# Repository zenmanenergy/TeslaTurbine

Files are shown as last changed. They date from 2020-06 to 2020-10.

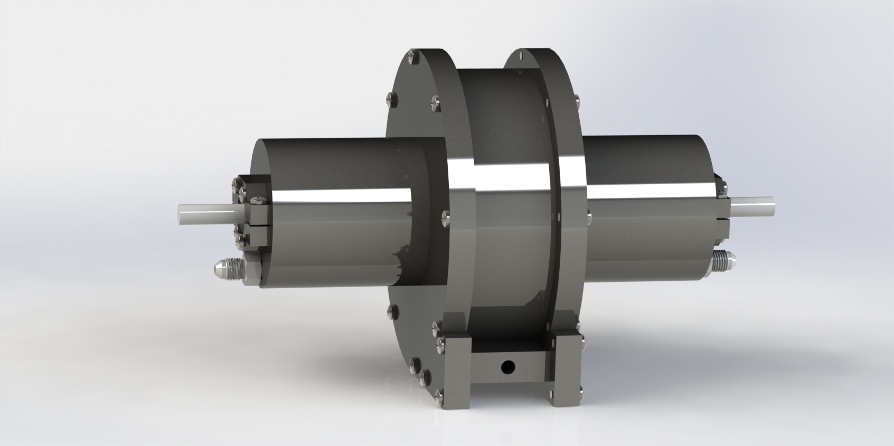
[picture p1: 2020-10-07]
Pump/138mm/Solidworks 2015/renderings/Tesla Pump2.JPG

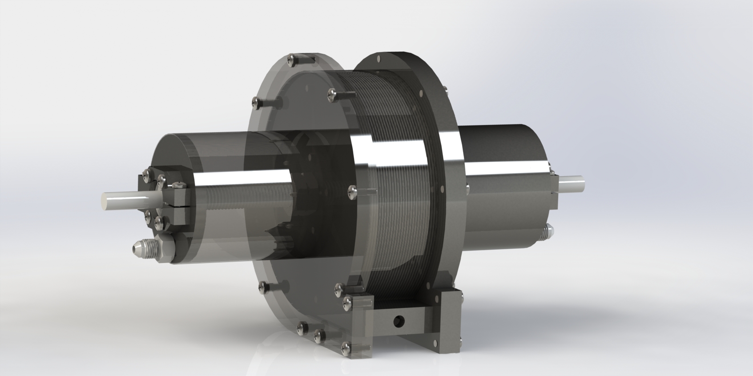
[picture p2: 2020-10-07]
Pump/138mm/Solidworks 2015/renderings/Tesla Pump transparent.JPG

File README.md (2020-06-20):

# Tesla Turbine and Pump

*this is a work in progress, please fork this repository and help edit the README files!*

Nikola Tesla's turbine is a unique turbine in that it does not contain any buckets or blades. This turbine consists of a 'runner' of very thin, flat disks that are keyed to an axle. Each of the disks on the runner is seperated from the other disks with a thin star shaped spacer. Near the axle, each disks contains 8 holes in them. Unlike bucket and blade style turbines, the Tesla turbine works based on a fluid's properties of viscosity and adhesion. 

The turbine operates in two modes. If the axle is spun using another mechanical device, such as a motor, it becomes a pump. In this mode it sucks water into the holes near the center of the disk and ejects the fluid from the tangent of the disks. If a high velocity fluid is injected at the tangent of the disks it becomes a turbine. In this mode the fluid causes the axle to spin at a high velocity.

## What is this repository?

This repository is made up of CAD drawings based on Tesla's patents. These drawings can be used to machine full scale turbines and pumps. Some very minor liberties have been taken in his patents primarily for ease of machinability. The current design is based on a layered approach, cutting parts with a laser cutter instead of a CNC mill. This method should dramatically reduce the time needed to machine parts. 

> `All drawings are done in metric!`

## File format

Originally these drawings were made using Solidworks 2015. Since Solidworks is not a free CAD tool, additional file formats are included in the repository including STL and DXF. As this repository grows additional formats will be included.

# More about Tesla Turbine

## Patents

> 1913 Patents

> 1921 Patent

## Turbine Mode

## Pump Mode

## History of the Tesla Turbine

## Quotes
*The idea on which all steam engines - gas engines, too - have been built in the past was that there must be something solid and substantial for the steam to push against. The piston of a reciprocating engine and the blades and buckets of modern turbine engines are examples. That idea has made them rather complicated devices, requiring careful fitting for efficient operation, great expense for repairs and especially in the case of turbines, great liability to damage. It has also made them bulky and heavy.*

*What I have done is to discard entirely the idea that there must be a solid wall in front of the steam and to apply in a practical way, for the first time, two properties which every physicist knows to be common to all fluids (including steam and gas) but which have not been utilized. These are adhesion and viscosity.*

*You know that water has a tendence to stick to a solid surface. That is the property of adhesion which every fluid - gas, steam, water or whatever it be- possesses. You also know that a drop of water tends to retain its form, even against a considerable force, such as gravity. That is viscosity, the tendency to resist molecular separation, and all the fluids have this property too.*

*It occured to me that if I should take circular disks, mount them on a shaft through their centers, space them a little distance apart and let some fluid under pressure, such as steam or gas, enter the interstices between the disks in a tangential direction, the fluid, as it moved, owing to these property of adhesion and viscosity, would tend to drag the disks along and transmit its energy to them. It happened just as I had thought it would, and that is the principle of this turbine. It utilitizes the very properties which cause all the loss of power in other turbines.*

-Nikola Tesla, March 1920 

## Traditional Turbines
Most turbines work using a principle known as impulse or reaction. An impulse turbine such as a Pelton wheel or a Crossflow turbine work when a high velocity fluid strikes a bucket (Pelton wheel) or a twist blade (Crossflow turbine). A reaction turbine such as a Francic wheel or a Curtis turbine work using a curved blade that produces a lift force creating a higher speed than an impulse turbine.

## Advantages of Tesla Turbine over Traditional Turbines

5/16" shaft:
abec-5 Bearings:
rated for 48,000 RPM
https://www.mcmaster.com/57155K338

5/16" washers:
316 stainless steel
https://www.mcmaster.com/90107A030

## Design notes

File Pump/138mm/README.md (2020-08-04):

## 138mm Pump

> As of 6/23/2020

These are drawings for a Tesla Pump that have 138mm diameter disks. They are based on a mixture of the patents from the 1921 runner. This is a modification from the 100mm disk. It does not contain a volute casing. I learned that the volute casing is the most expensive part to machine. So I have opted to use tubing instead allowing for a larger number of disks. All parts except for the axle and the tube section of the stator are designed to be laser cut out of flat stock and should not require any CNC machining. Once the parts are laser cut, many of them need to be welded together to seal the joints. 

I plan to use a mixture of metals on this pump. I will use Stainless steel 304 for the disks, spacers and axle. For the stator I will use aluminum. Aluminum is a tricky to weld. I will use a MIG spool gun to weld the joints.

The bearing mount is designed to all the runner AND bearings to be easily removed from the stator while still press fitting the axle onto the bearings. There is no threaded nut necessary for the axle, when the bearing mounts are bolted to the stator it will (should) squeeze the disks together. The 4 holes in the bearing mount need to be tapped for an M5 bolt.

Because the diameter of this turbine is small, to get the edge up to a high enough velocity means it requires high speed bearings. The bearings in these drawings can be purchased from mcmastercarr.com They are part number: 57155K338 rated for 48,000 rpm.

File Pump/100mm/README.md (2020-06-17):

## 100mm Pump

> As of 6/16/2020

These are drawings for a Tesla Pump that have 100mm diameter disks. They are based on a mixture of the patents from the 1913 stator and 1921 runner. I made some very minor design changes in the stator for ease of machining. All parts except for the axle are designed to be laser cut out of flat stock and should not require any CNC machining. Once the parts are laser cut, many of them need to be welded together to seal the joints. 

The bearing mount is designed to all the runner AND bearings to be easily removed from the stator while still press fitting the axle onto the bearings. There is no threaded nut necessary for the axle, when the bearing mounts are bolted to the stator it will (should) squeeze the disks together. The 4 holes in the bearing mount need to be tapped for an M5 bolt.

Because the diameter of this turbine is small, to get the edge up to a high enough velocity means it requires high speed bearings. The bearings in these drawings can be purchased from mcmastercarr.com They are part number: 57155K338 rated for 48,000 rpm.

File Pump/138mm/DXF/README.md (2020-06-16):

## Solidworks 2015 drawings

The assembly for the Tesla Pump is in the /Tesla Pump folder. Some of the files are shared across the Turbine and pump. This folder structure helps to reduce duplicated work.

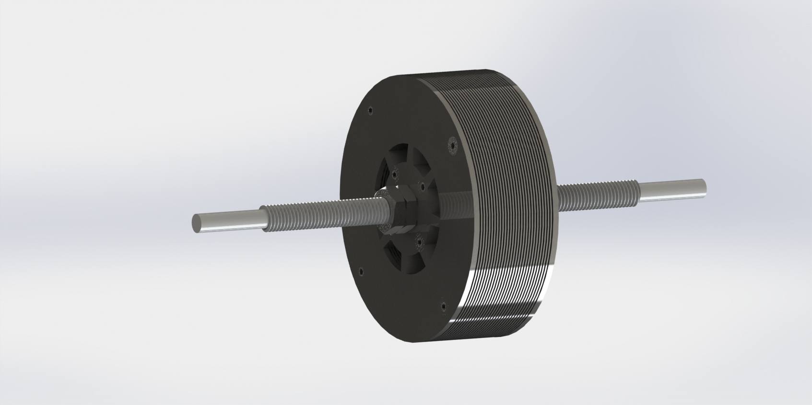
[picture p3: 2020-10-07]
Pump/138mm/Solidworks 2015/renderings/rotor.JPG

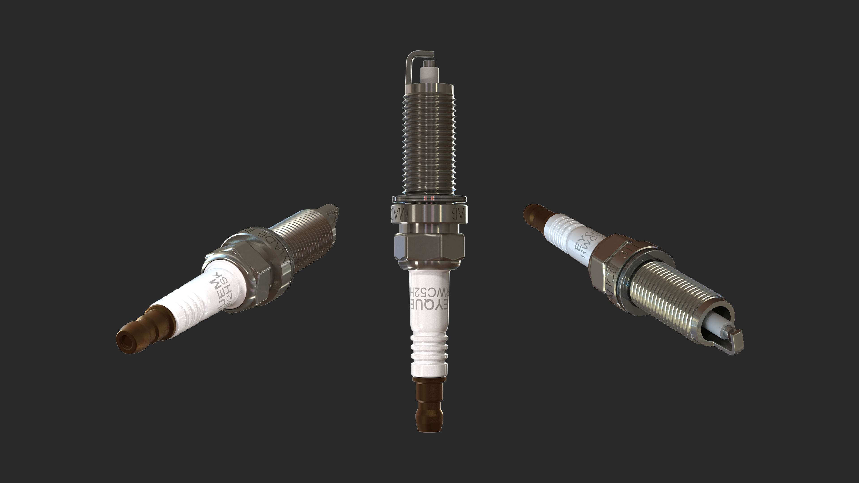
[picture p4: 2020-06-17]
Pulsejet/200mm/DXF/detonation chamber/spark-plug-61.snapshot.13/Renderings/Spark Plug - 3 view.png

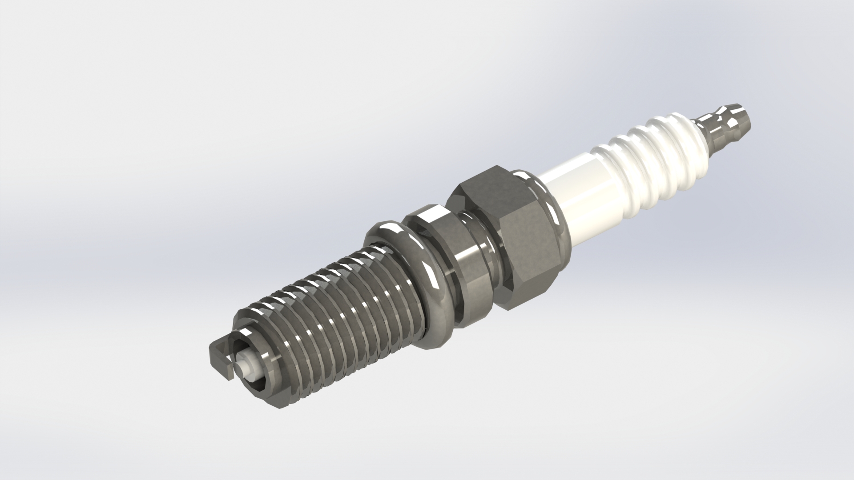
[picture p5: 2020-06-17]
Pulsejet/200mm/DXF/detonation chamber/Spark Plugs/preview 1.JPG

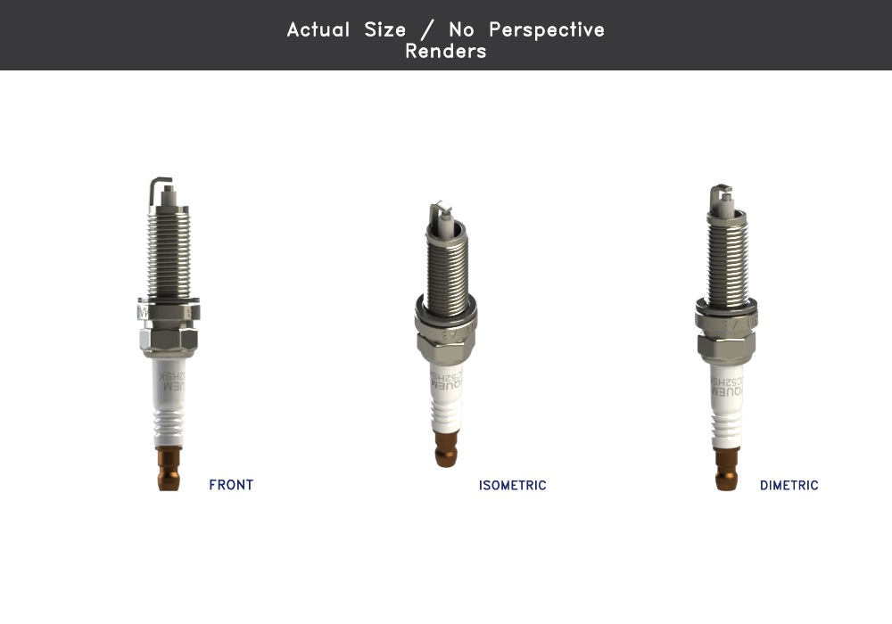
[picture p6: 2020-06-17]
Pulsejet/200mm/DXF/detonation chamber/spark-plug-61.snapshot.13/Renderings/Spark actual copy.png

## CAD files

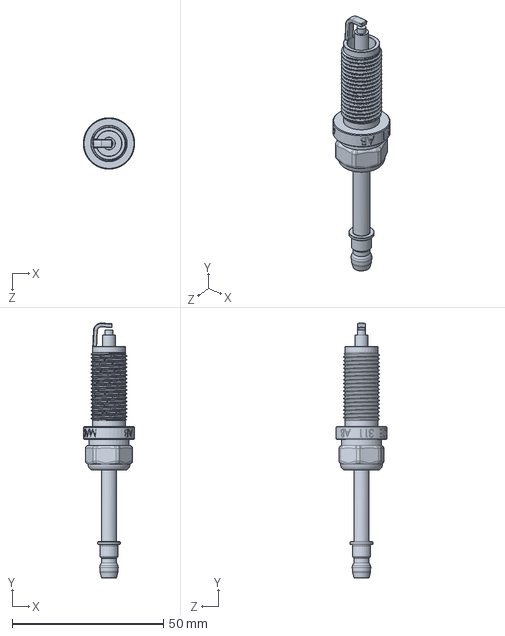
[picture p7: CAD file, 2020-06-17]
Pulsejet/200mm/DXF/detonation chamber/Spark Plugs/spark plug 1/Spark Plug - Main Body.SLDPRT
17.0 x 84.3 x 17.0 mm

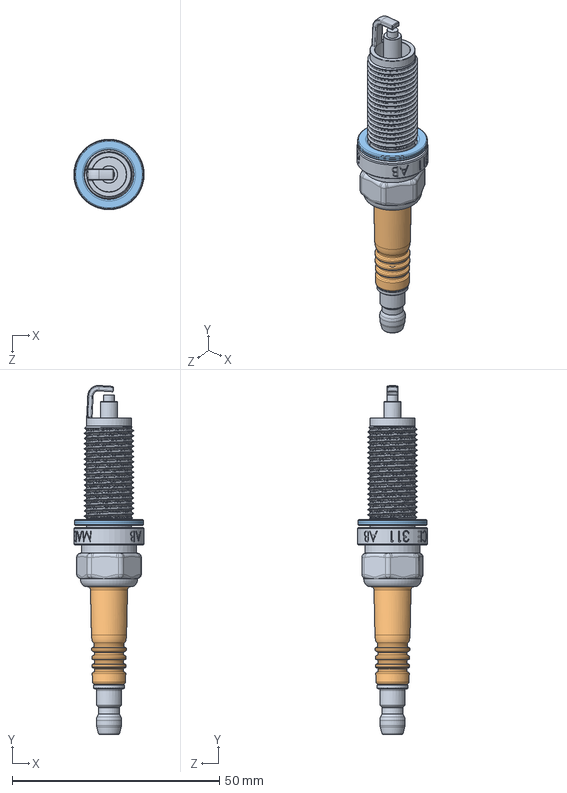
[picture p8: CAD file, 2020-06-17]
Pulsejet/200mm/DXF/detonation chamber/spark-plug-61.snapshot.13/Assembly/Spark Plug - assembly.SLDASM
17.0 x 84.3 x 17.0 mm
Spark Plug - Main Body
Insulator
Washer

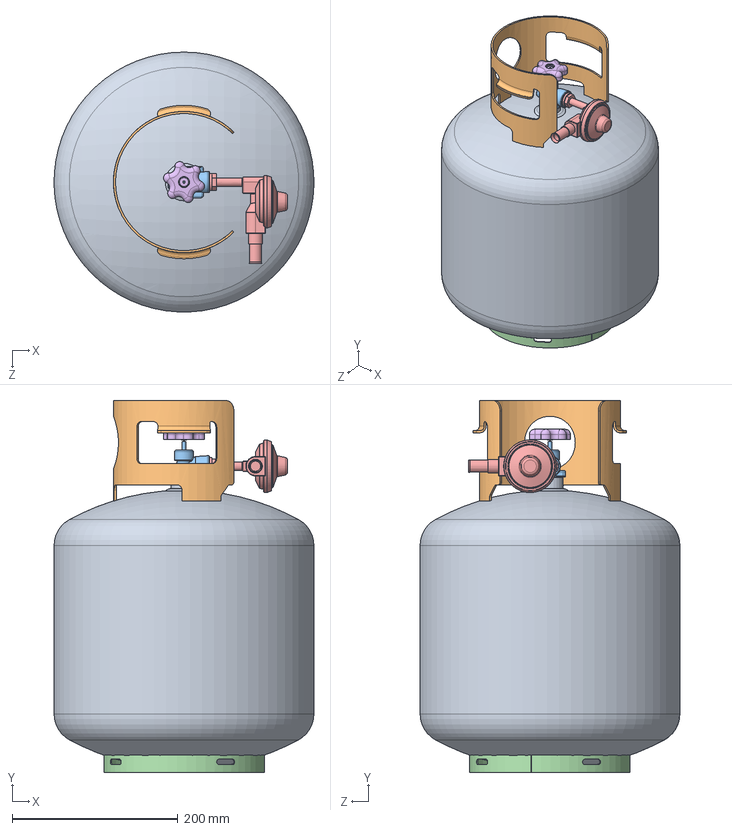
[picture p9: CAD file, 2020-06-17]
Pulsejet/200mm/Solidworks 2015/pipe fittings/Propane Tank/User Library-BBQ Liquid Propane Tank Assembly.SLDASM
313.2 x 448.3 x 313.1 mm
tank body2
tank_lifting_ring2
tank_valve_body2
tank_support_ring2
regulator2
gas_valve_knob2

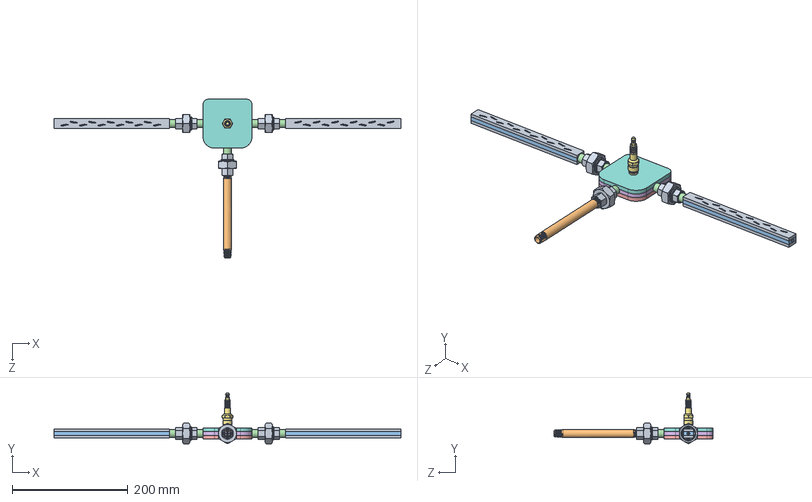
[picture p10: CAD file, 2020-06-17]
Pulsejet/200mm/Solidworks 2015/pulsejet/pulsejet.SLDASM
600.0 x 87.6 x 274.7 mm
bottom x 4
diverter x 22
channel x 2
9157K110_STD-WALL 304-304L SS THRD ONE END PIPE NIPPLE x 5
detonation bottom
detonation middle
SW3dPS
detonation top
4464K484_TYPE 304 STAINLESS STL THREADED PIPE FITTING x 3
4830K138_STANDARD-WALL 304 304L SS PIPE NIPPLE

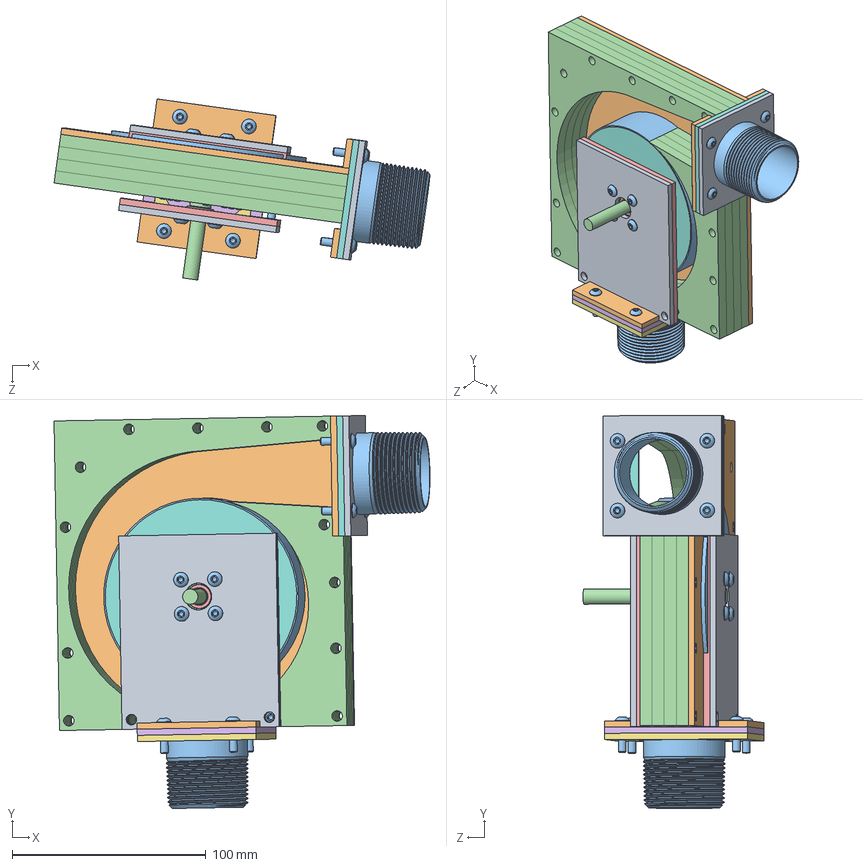
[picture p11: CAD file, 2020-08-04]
Pump/100mm/Solidworks 2015/Tesla Pump/Tesla Pump.SLDASM
194.3 x 203.1 x 93.6 mm
housing exhaust 1
housing1
socket button head cap screw_am x 17
housing 5 x 4
housing exhaust 2 x 2
input mount 1
input mount 2
exhaust mount 1
exhaust mount 2
exhaust bolt plate x 4
9157K260_STD-WALL 304-304L SS THRD ONE END PIPE NIPPLE x 2
axle
disk 1 x 13
spacer 1 x 14
keyway x 2
disk 0 x 2
92000A054_18-8 SS METRIC PAN HEAD PHIL MACHINE SCREW x 8
94150A305_TYPE 316 STAINLESS STEEL HEX NUT x 8
bearing mount 1 x 2
57155K338_STAINLESS STEEL BALL BEARING x 2

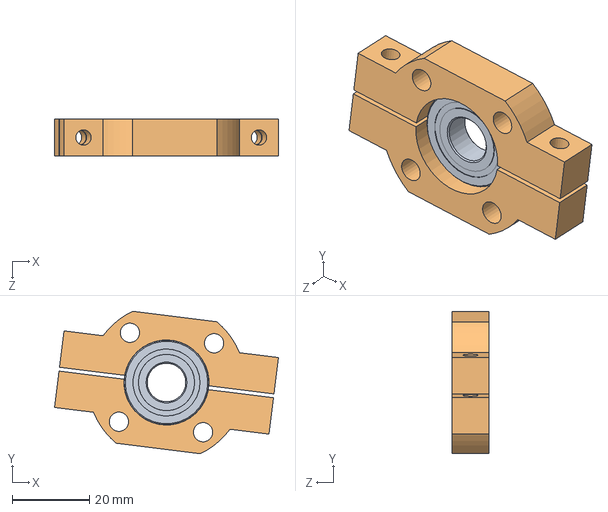
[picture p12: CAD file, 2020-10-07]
Pump/138mm/Solidworks 2015/bearing mount/bearing mount.SLDASM
58.1 x 36.9 x 9.50 mm
5972K164_BALL BEARING
bearing compression mount x 2

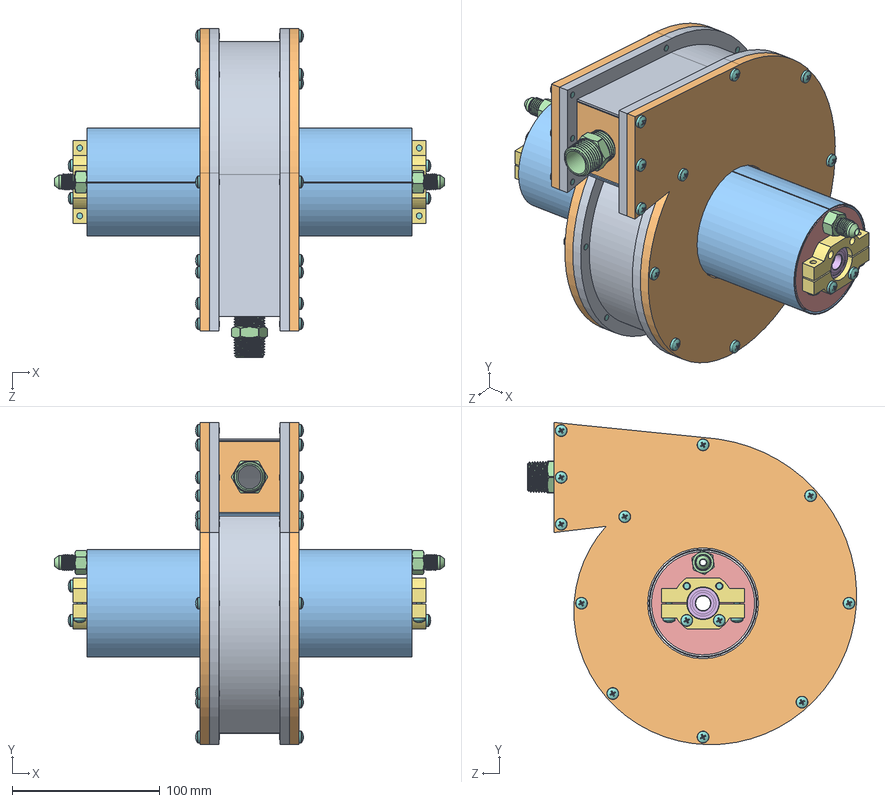
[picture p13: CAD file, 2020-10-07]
Pump/138mm/Solidworks 2015/pump stator/pump stator.SLDASM
263.7 x 217.9 x 222.6 mm
mounting ring x 2
end plate x 2
bearing pipe x 2
50695K162_STEEL 37 DEGREE FLARED TUBE FITTING x 2
tube end plate x 2
5972K164_BALL BEARING x 2
bearing compression mount x 4
pan cross head_am x 32
rolled housing
exhaust plate
exhaust plate top
4464K741_304 STAINLESS STEEL THREADED PIPE FITTING

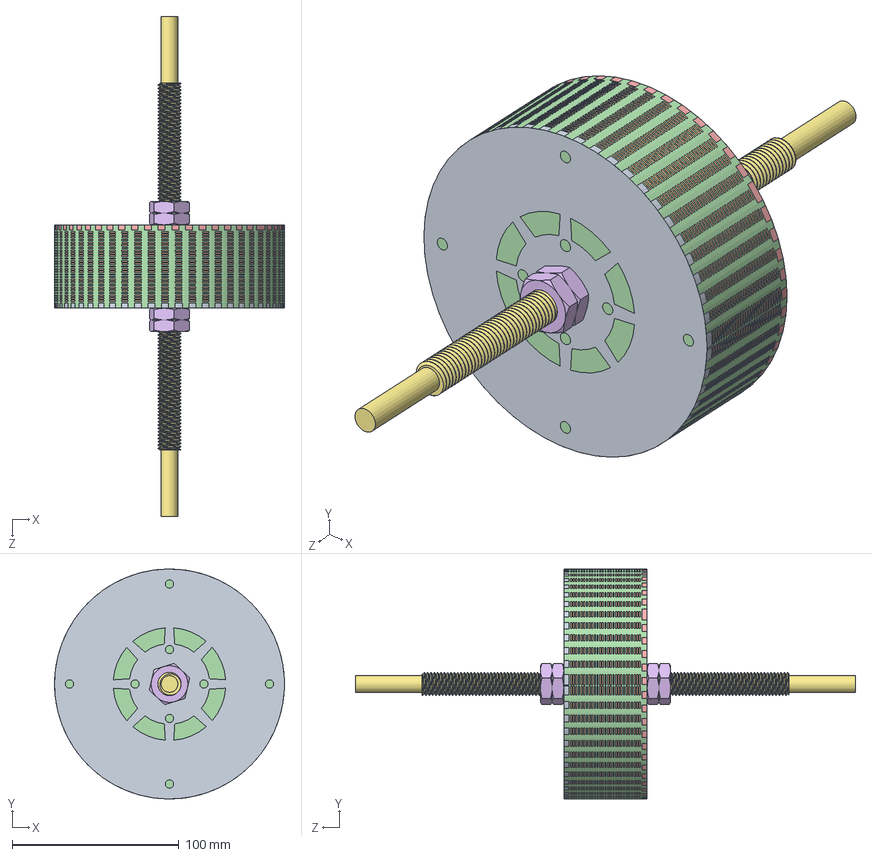
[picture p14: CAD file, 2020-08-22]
Pump/138mm/Solidworks 2015/rotor/rotor.SLDASM
138.0 x 138.0 x 300.0 mm
spacer 1 x 28
disk 1 x 27
keyway x 2
rotating part for simulation^rotor
disk x
90710A135_TYPE 18-8 SS THIN HEX NUT - DIN 439B x 4
axle
item_0060029_countersunk_screw_din_7991_m5x50_details_3 x 8
disk 0

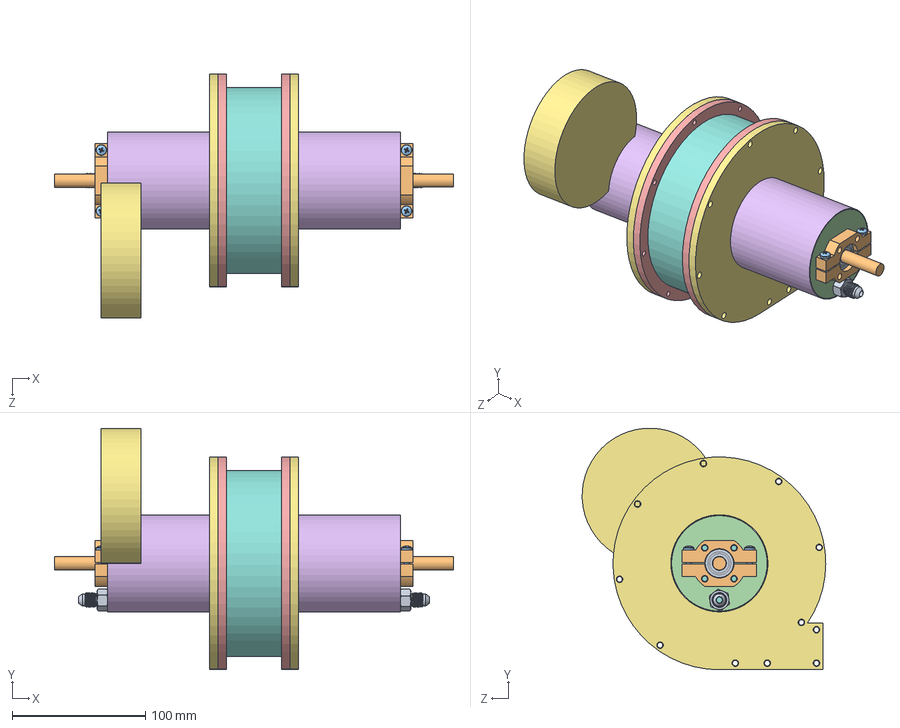
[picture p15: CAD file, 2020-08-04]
Pump/138mm/Solidworks 2015/Tesla Pump/Tesla Pump.SLDASM
300.0 x 181.6 x 183.1 mm
50695K162_STEEL 37 DEGREE FLARED TUBE FITTING x 2
exhaust plate top
exhaust plate
tube end plate x 2
mounting ring x 2
bearing pipe x 2
end plate 1 x 2
rolled housing
5972K164_BALL BEARING x 2
bearing compression mount x 4
pan cross head_am x 4
spacer 1 x 28
disk 1 x 27
keyway x 2
disk x
90710A135_TYPE 18-8 SS THIN HEX NUT - DIN 439B x 4
axle
item_0060029_countersunk_screw_din_7991_m5x50_details_3 x 8
disk 0

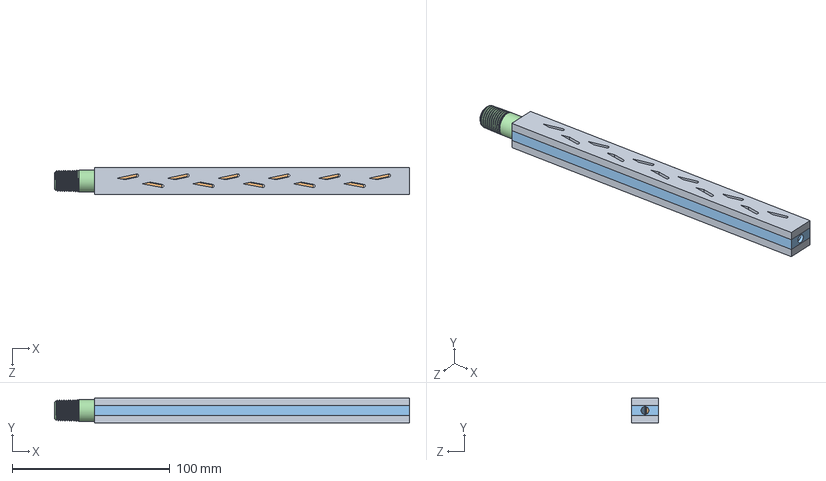
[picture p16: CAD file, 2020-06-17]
Pulsejet/200mm/Solidworks 2015/valvular conduit/valvular conduit.SLDASM
225.4 x 15.8 x 17.1 mm
bottom x 2
diverter x 11
channel
9157K110_STD-WALL 304-304L SS THRD ONE END PIPE NIPPLE

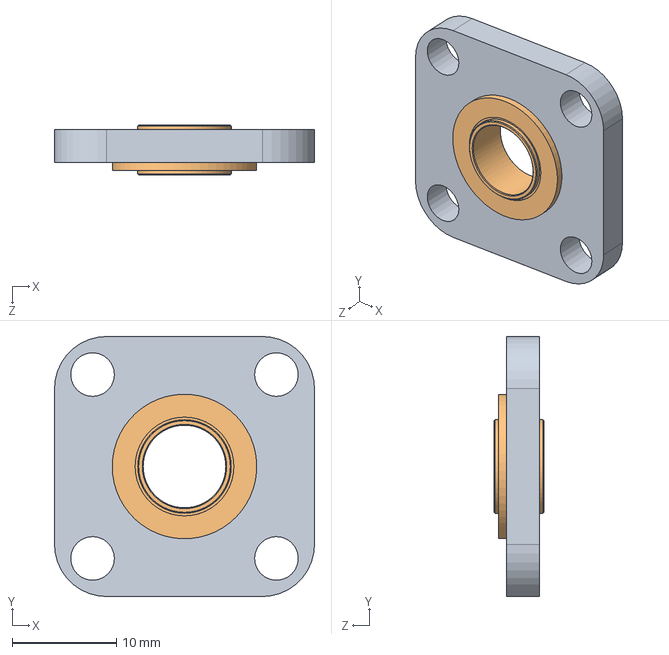
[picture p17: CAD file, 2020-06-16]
Pump/100mm/Solidworks 2015/bearing mount/bearing mount.SLDASM
25.0 x 25.0 x 4.78 mm
bearing mount 1
57155K338_STAINLESS STEEL BALL BEARING

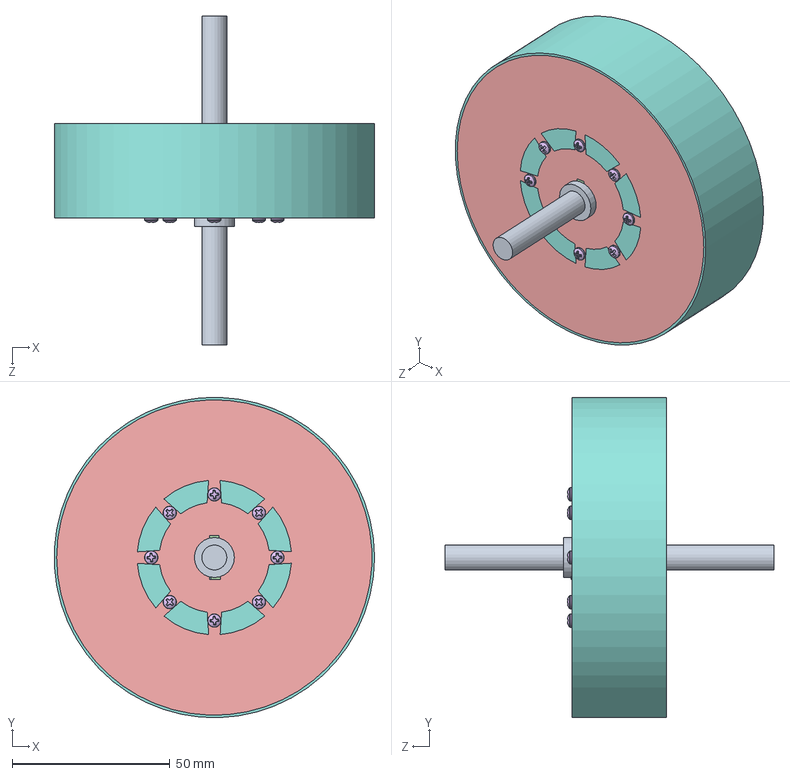
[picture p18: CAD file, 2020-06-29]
Pump/100mm/Solidworks 2015/rotor/rotor.SLDASM
101.5 x 101.6 x 104.3 mm
axle
disk 1 x 13
spacer 1 x 14
keyway x 2
disk 0 x 2
92000A054_18-8 SS METRIC PAN HEAD PHIL MACHINE SCREW x 8
94150A305_TYPE 316 STAINLESS STEEL HEX NUT x 8

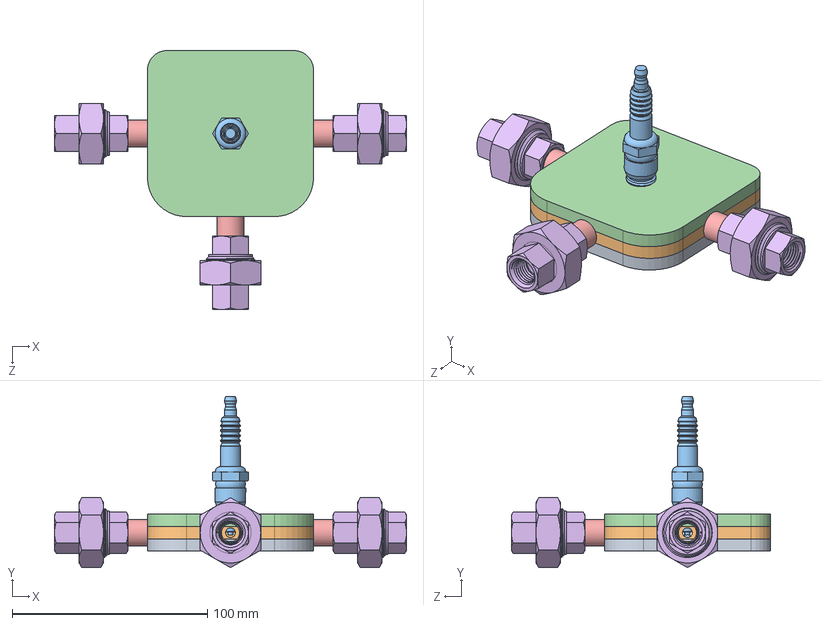
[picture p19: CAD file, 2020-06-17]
Pulsejet/200mm/Solidworks 2015/detonation chamber/detonation chamber.SLDASM
180.1 x 87.6 x 132.5 mm
detonation bottom
detonation middle
SW3dPS
detonation top
9157K110_STD-WALL 304-304L SS THRD ONE END PIPE NIPPLE x 3
4464K484_TYPE 304 STAINLESS STL THREADED PIPE FITTING x 3

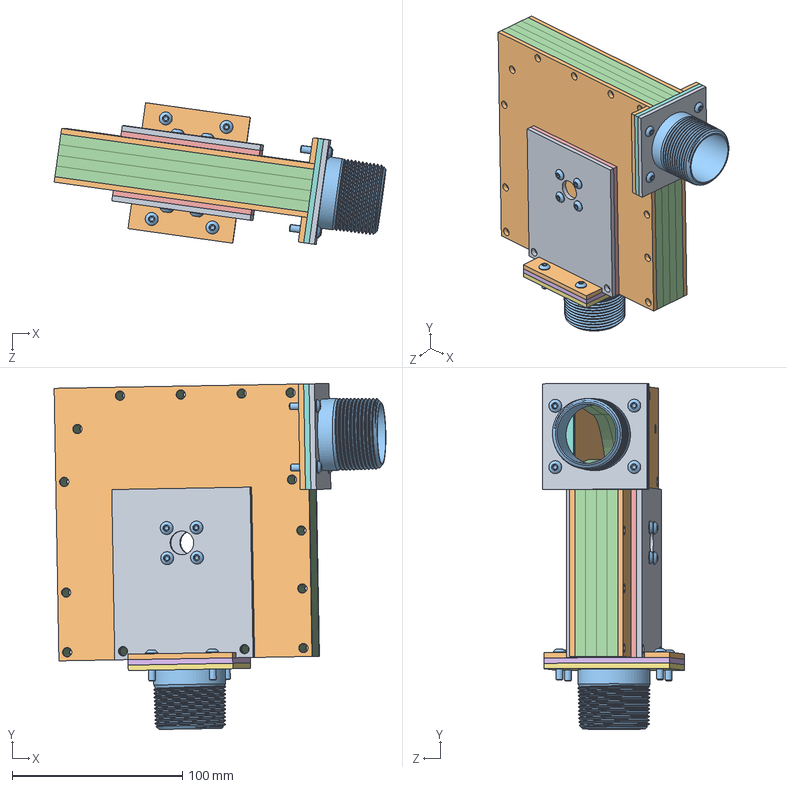
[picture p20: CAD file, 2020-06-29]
Pump/100mm/Solidworks 2015/pump stator/pump stator.SLDASM
194.7 x 203.1 x 83.1 mm
housing1 x 2
housing exhaust 1 x 2
socket button head cap screw_am x 16
housing 5 x 4
housing exhaust 2 x 2
input mount 1
input mount 2
exhaust mount 1
exhaust mount 2
exhaust bolt plate x 4
9157K260_STD-WALL 304-304L SS THRD ONE END PIPE NIPPLE x 2

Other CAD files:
Pulsejet/200mm/DXF/detonation chamber/spark-plug-61.snapshot.13/Step - Igs/Spark Plug - assembly.STEP
Pulsejet/200mm/DXF/detonation chamber/Spark Plugs/spark plug 1/spark plug 1.SLDASM
Pulsejet/200mm/DXF/detonation chamber/combustion chamber.SLDASM
Pump/138mm/Solidworks 2015/magnetic bearings/magnetic bearings.SLDASM
Pulsejet/200mm/DXF/detonation chamber/SW3dPS-spark plug/SW3dPS.SLDPRT
Pulsejet/200mm/DXF/detonation chamber/Spark Plugs/Spark Plug.SLDPRT
Pulsejet/200mm/DXF/detonation chamber/Spark Plugs/Spark Plug.STEP
Pulsejet/200mm/DXF/detonation chamber/Spark Plugs/spark plug 1/Insulator.sldprt
Pulsejet/200mm/DXF/detonation chamber/Spark Plugs/spark plug 1/Washer.SLDPRT
Pulsejet/200mm/DXF/detonation chamber/chamber walls.SLDPRT
Pulsejet/200mm/DXF/detonation chamber/combustion bottom.SLDPRT
Pulsejet/200mm/DXF/detonation chamber/combustion chamber with propane.SLDASM
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

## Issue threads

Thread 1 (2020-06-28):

Remove the curves

zenmanenergy, 2020-06-28:
The curves are a pain in the neck to weld! Remove them. Replace with more straight lines.

Closed 2020-06-29.

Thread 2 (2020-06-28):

Weld the square stock onto the axle

zenmanenergy, 2020-06-28:
Remove the notch for the square stock on the axle. Just increase the size of the square hole in the disks so the square stock can sit on the tangent of the axle. Weld it into place.

This requires one fewer operations.

zenmanenergy, 2020-08-21:
In the 138mm version I switched to a 14mm threaded rod for the axle. I used a lathe to turn the ends of the axle down to a dimension that fits inside of the ball bearings.

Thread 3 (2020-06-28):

Input mount 2 doesn't fit

zenmanenergy, 2020-06-28:
The input mount 2 does not fit the 1-1/4" SS pipe nipple.

zenmanenergy, 2020-06-29:
1-1/4" is kind of big for this size turbine, maybe it should be smaller?

Closed 2020-06-29.

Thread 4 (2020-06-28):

exhaust mount 2 doesn't fit

zenmanenergy, 2020-06-28:
The exhaust mount 2 does not fit the 1-1/4" SS pipe nipple.

zenmanenergy, 2020-06-29:
1-1/4" is kind of big for this size turbine, maybe it should be smaller?

Closed 2020-06-29.

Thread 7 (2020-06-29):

Bolt for housing1 and housing exhaust

zenmanenergy, 2020-06-29:
make housing1 and housing exhaust wider so they overlap the two bolt holts at the bottom. Then use these as a way to correctly align the plates.

Closed 2020-06-29.

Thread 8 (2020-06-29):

Swap 1/2" for two- 1/4" housing5

zenmanenergy, 2020-06-29:
Housing5 is currently 1/2" thick and there are 2 of them.

It turns out that it is 50% cheaper to use 2x   1/4" thick plates instead of 1x  1/2" thick. It requires extra welding.

Closed 2020-06-29.

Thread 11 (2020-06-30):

bolt holes in housing 1 too small

zenmanenergy, 2020-06-30:
the bolt holes in housing 1 need to be at least 5mm

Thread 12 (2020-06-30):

Too tight!

zenmanenergy, 2020-06-30:
I have assembled the turbine and it seems to be too tight. I'm not sure what is hitting, but it doesn't want to spin.

There needs to be a way to adjust the horizontal pressure on the bearings.

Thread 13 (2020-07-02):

Use bolts when welding

zenmanenergy, 2020-07-02:
Use bolts to hold parts together while welding to reduce the metal from warping and bending.

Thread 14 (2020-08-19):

Housing dimensions too small

zenmanenergy, 2020-08-19:
The housing diameter is too small and hits the edges of the disks.

zenmanenergy, 2020-08-21:
The housing has been updated to match the volute shape in patent 1,061,142

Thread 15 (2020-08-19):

Tube End plate diameter too big

zenmanenergy, 2020-08-19:
The diameter of tube end plate is too large to fit inside the bearing pipe.

zenmanenergy, 2020-08-21:
This is in the next update.

The diameter of the tube end plate is now 69.75mm

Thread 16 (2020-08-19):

bearing pipe too big

zenmanenergy, 2020-08-19:
When the bearing pipe is slip rolled, the length is too long to fit inside the  hole in the end plate. I had to grind it down to reduce the length.

zenmanenergy, 2020-08-21:
This is in the next update.

The tube end plate diameter has been reduced to 69.75mm and the hole for end plate is increased to 75mm.

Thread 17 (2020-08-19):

Bearing alignment

zenmanenergy, 2020-08-19:
The bearing compression mount needs to somehow be vertially/horizontally adjustable so the axles are aligned and the disks are parallel to the inside of the housing.

zenmanenergy, 2020-08-21:
I still don't have a good answer for this. I bought some magnets, I will try magnetic bearings in a future update.

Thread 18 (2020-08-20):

overlap exhaust plate top

zenmanenergy, 2020-08-20:
Overlap the exhaust plate top with the exhaust plate to improve the weld joint

zenmanenergy, 2020-08-21:
This is in the next update

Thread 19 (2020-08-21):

Increase Diameter of exhaust hole

zenmanenergy, 2020-08-21:
Increase the diameter of the exhaust hole to handle a 1/2" NPT thread.

zenmanenergy, 2020-08-21:
This is in the next update

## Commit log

2020-05-21 notes about bearings
2020-06-16 Initial 100mm Tesla pump
    [4464K471_TYPE 304 STAINLESS STL THREADED PIPE FITTING.SLDPRT, 4464K484_TYPE 304 STAINLESS STL THREADED PIPE FITTING.SLDPRT, 4464K497_TYPE 304 STAINLESS STL THR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]
2020-06-16 Moved folders
    [4464K471_TYPE 304 STAINLESS STL THREADED PIPE FITTING.SLDPRT, 4464K484_TYPE 304 STAINLESS STL THREADED PIPE FITTING.SLDPRT, 4464K497_TYPE 304 STAINLESS STL THR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]
2020-06-16 changed bearing mount drill hole size
    [bearing mount 1.SLDPRT, bearing mount.SLDASM]
2020-06-16 disk diameter
    updated the disk diameter.
    [Tesla Pump.SLDASM, disk 0.SLDPRT, disk 1.SLDPRT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]
2020-06-16 Created DXF folder
    I created a new DXF folder and exported all solidworks parts to DXF format.
    [Tesla Pump.SLDASM, User Library-Configurable Compression Spring.STEP, axle.SLDPRT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]
2020-06-16 Created Pump and Turbine folders
    I moved all the 100mm files for the pump into a pump folder. I created a turbine folder, but it is currently empty.
    [4464K471_TYPE 304 STAINLESS STL THREADED PIPE FITTING.SLDPRT, 4464K484_TYPE 304 STAINLESS STL THREADED PIPE FITTING.SLDPRT, 4464K497_TYPE 304 STAINLESS STL THR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]
2020-06-17 Added pulsejet drawings
    [4464K471_TYPE 304 STAINLESS STL THREADED PIPE FITTING.SLDPRT, 4464K484_TYPE 304 STAINLESS STL THREADED PIPE FITTING.SLDPRT, 4464K497_TYPE 304 STAINLESS STL THR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]
2020-06-29 housing 1 and exhaust
    removed curves on housing 1 and exhaust, added bolt holes
    fix #7
    fix #1
    fix #6
    [housing exhaust 2.SLDPRT, housing1.SLDPRT]
2020-06-29 pipe nipples
    fix #10
    [4464K471_TYPE 304 STAINLESS STL THREADED PIPE FITTING.SLDPRT, 4464K484_TYPE 304 STAINLESS STL THREADED PIPE FITTING.SLDPRT, 4464K497_TYPE 304 STAINLESS STL THR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]
2020-06-29 exhaust mount fix
    fix #4
    [exhaust mount 1.SLDPRT, exhaust mount 2.SLDPRT]
2020-06-29 input mount
    fix #3
    [input mount 1.SLDPRT, input mount 2.SLDPRT]
2020-06-29 updated mates
    updated mates
    [Tesla Pump.SLDASM, axle.SLDPRT, pump stator.SLDASM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]
2020-06-29 switched 12.7mm for 6.35mm
    fix #8
    [housing 5.SLDPRT]
2020-06-29 removed curves
    removed curves and widened
    [housing1.SLDPRT]
2020-08-04 Added laser cut version of the 138mm pump
    [4464K471_TYPE 304 STAINLESS STL THREADED PIPE FITTING.SLDPRT, 4464K484_TYPE 304 STAINLESS STL THREADED PIPE FITTING.SLDPRT, 4464K497_TYPE 304 STAINLESS STL THR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]
2020-08-04 DXF files for laser cutting
    [Flat pattern - bearing pipe.DXF, Flat pattern - rolled housing.DXF, bearing compression mount.DXF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]
2020-08-22 updated hardware
    [90710A135_TYPE 18-8 SS THIN HEX NUT - DIN 439B.SLDPRT, item_0060029_countersunk_screw_din_7991_m5x50_details_3.SLDPRT]
2020-08-22 change diameter
    #15
    [end plate.DXF]
2020-08-22 update dimensions
    Changed dimensions of the exhaust plate top
    #18
    [exhaust plate top.DXF]
2020-08-22 changed dimensions
    updated the dimensions of the exhaust plate to match the new mounting ring
    [exhaust plate.DXF]
2020-08-22 updated dxf
    [Flat pattern - rolled housing.DXF, mounting ring.DXF, tube end plate.DXF]
2020-08-22 new pipe fittings
    new input and exhaust pipes
    [4464K741_304 STAINLESS STEEL THREADED PIPE FITTING.SLDPRT, 50715K512_TYPE 316 SS 37 DEGREE FLARED TUBE FITTING.SLDPRT]
2020-08-22 adjustable bearing mount
    [bearing compression mount.SLDPRT, bearing mount.SLDASM]
2020-08-22 bearing pipe
    [bearing pipe.SLDPRT]
2020-08-22 updated end plate
    #14
    [end plate 1.SLDPRT, end plate.SLDPRT]
2020-08-22 updated exhaust plate
    #19
    [exhaust plate top.SLDPRT, exhaust plate.SLDPRT]
2020-08-22 updated mounting ring
    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
    [mounting ring.SLDPRT, pump stator.SLDASM, rolled housing.SLDPRT]
2020-08-22 updated end plate
    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
    [tube end plate.SLDPRT]
2020-08-22 updated rotor
    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
    [disk 0.SLDPRT, disk x.SLDPRT, rotor.SLDASM]
2020-08-22 updated tesla pump
    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
2020-10-07 Added magnetic bearing and DC motor
    [25x16x5 neodymium bearing.SLDPRT, Yaegoo DC motor JK-0232 24V 2700RPM.SLDPRT, bearing mount.SLDASM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]
